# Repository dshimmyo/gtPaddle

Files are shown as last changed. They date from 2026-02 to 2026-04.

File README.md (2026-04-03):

# gtPaddle
paddle controller for gametank design files

# Images
Original Arduino experimental paddle:

arduinoPaddle

Protoboard paddle:

protoboardPaddle

PCB render:

rendering of pcb

---

License
This hardware documentation is licensed under the TAPR Open Hardware License.

(C) 2026 DKS Interactive LLC.
Based on the GameTank hardware designed by Clyde Shaffer

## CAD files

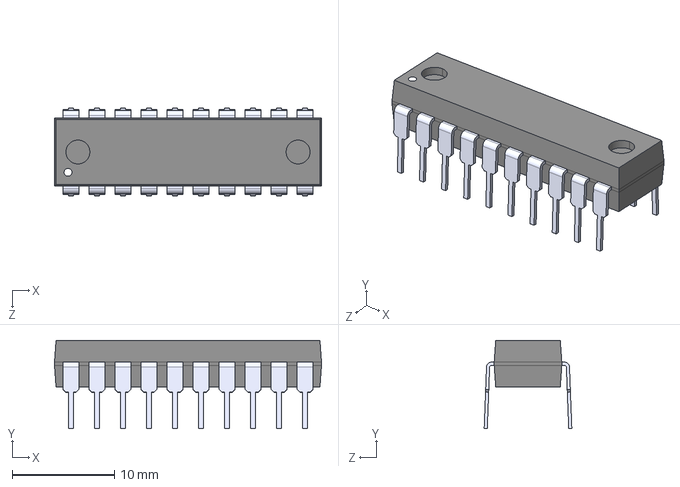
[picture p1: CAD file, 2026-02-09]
ADC0804LCN.step
26.1 x 8.64 x 8.56 mm

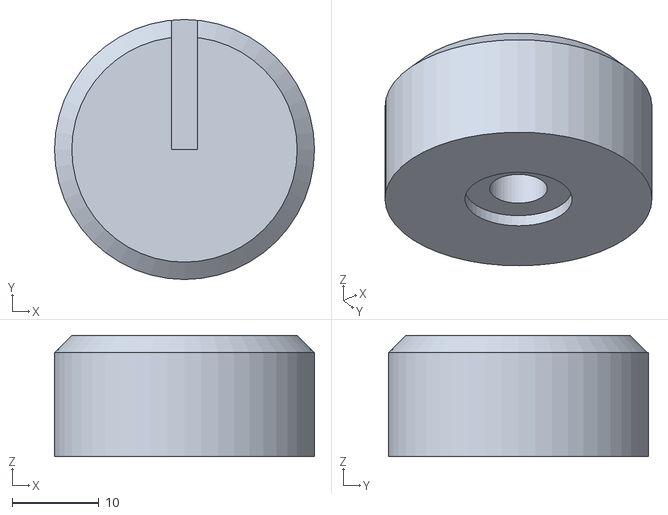
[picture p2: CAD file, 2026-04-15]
CAD/enclosure/2026-04-14/paddle knob 02.stl
30.0 x 30.0 x 14.0

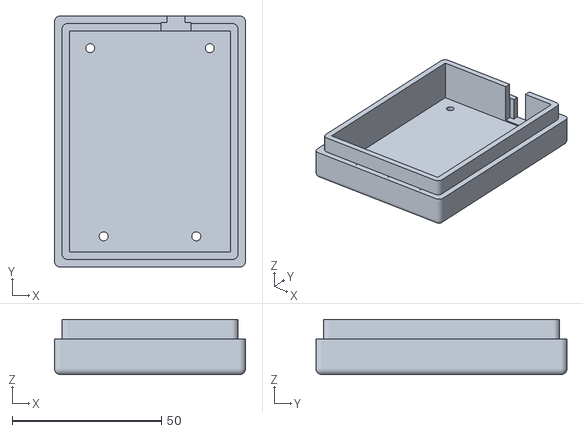
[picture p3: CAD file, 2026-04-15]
CAD/enclosure/2026-04-14/Paddle Enclosure 1 Bottom.stl
64.0 x 84.0 x 18.5

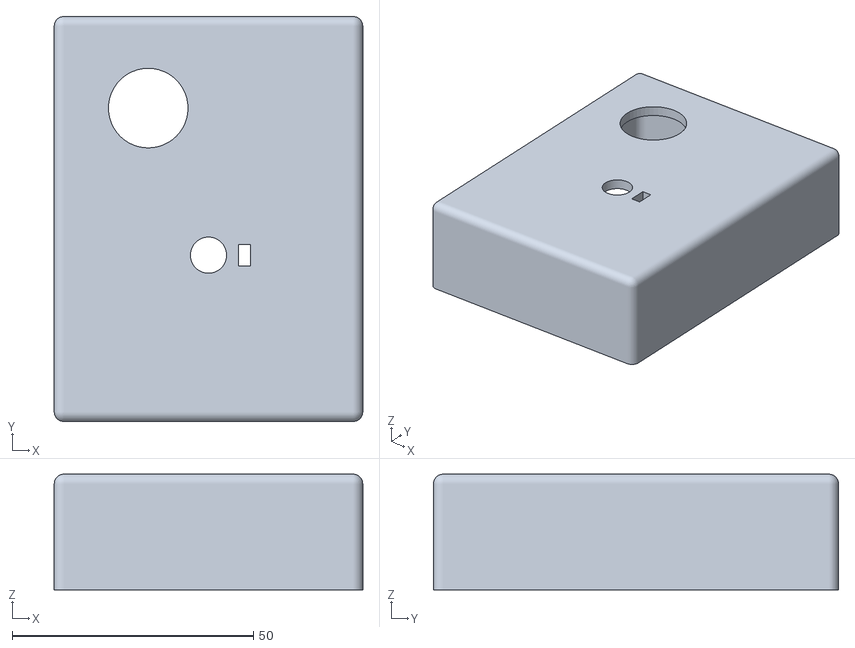
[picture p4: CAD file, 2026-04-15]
CAD/enclosure/2026-04-14/Paddle Enclosure 1.1 Top.stl
64.0 x 84.0 x 24.0

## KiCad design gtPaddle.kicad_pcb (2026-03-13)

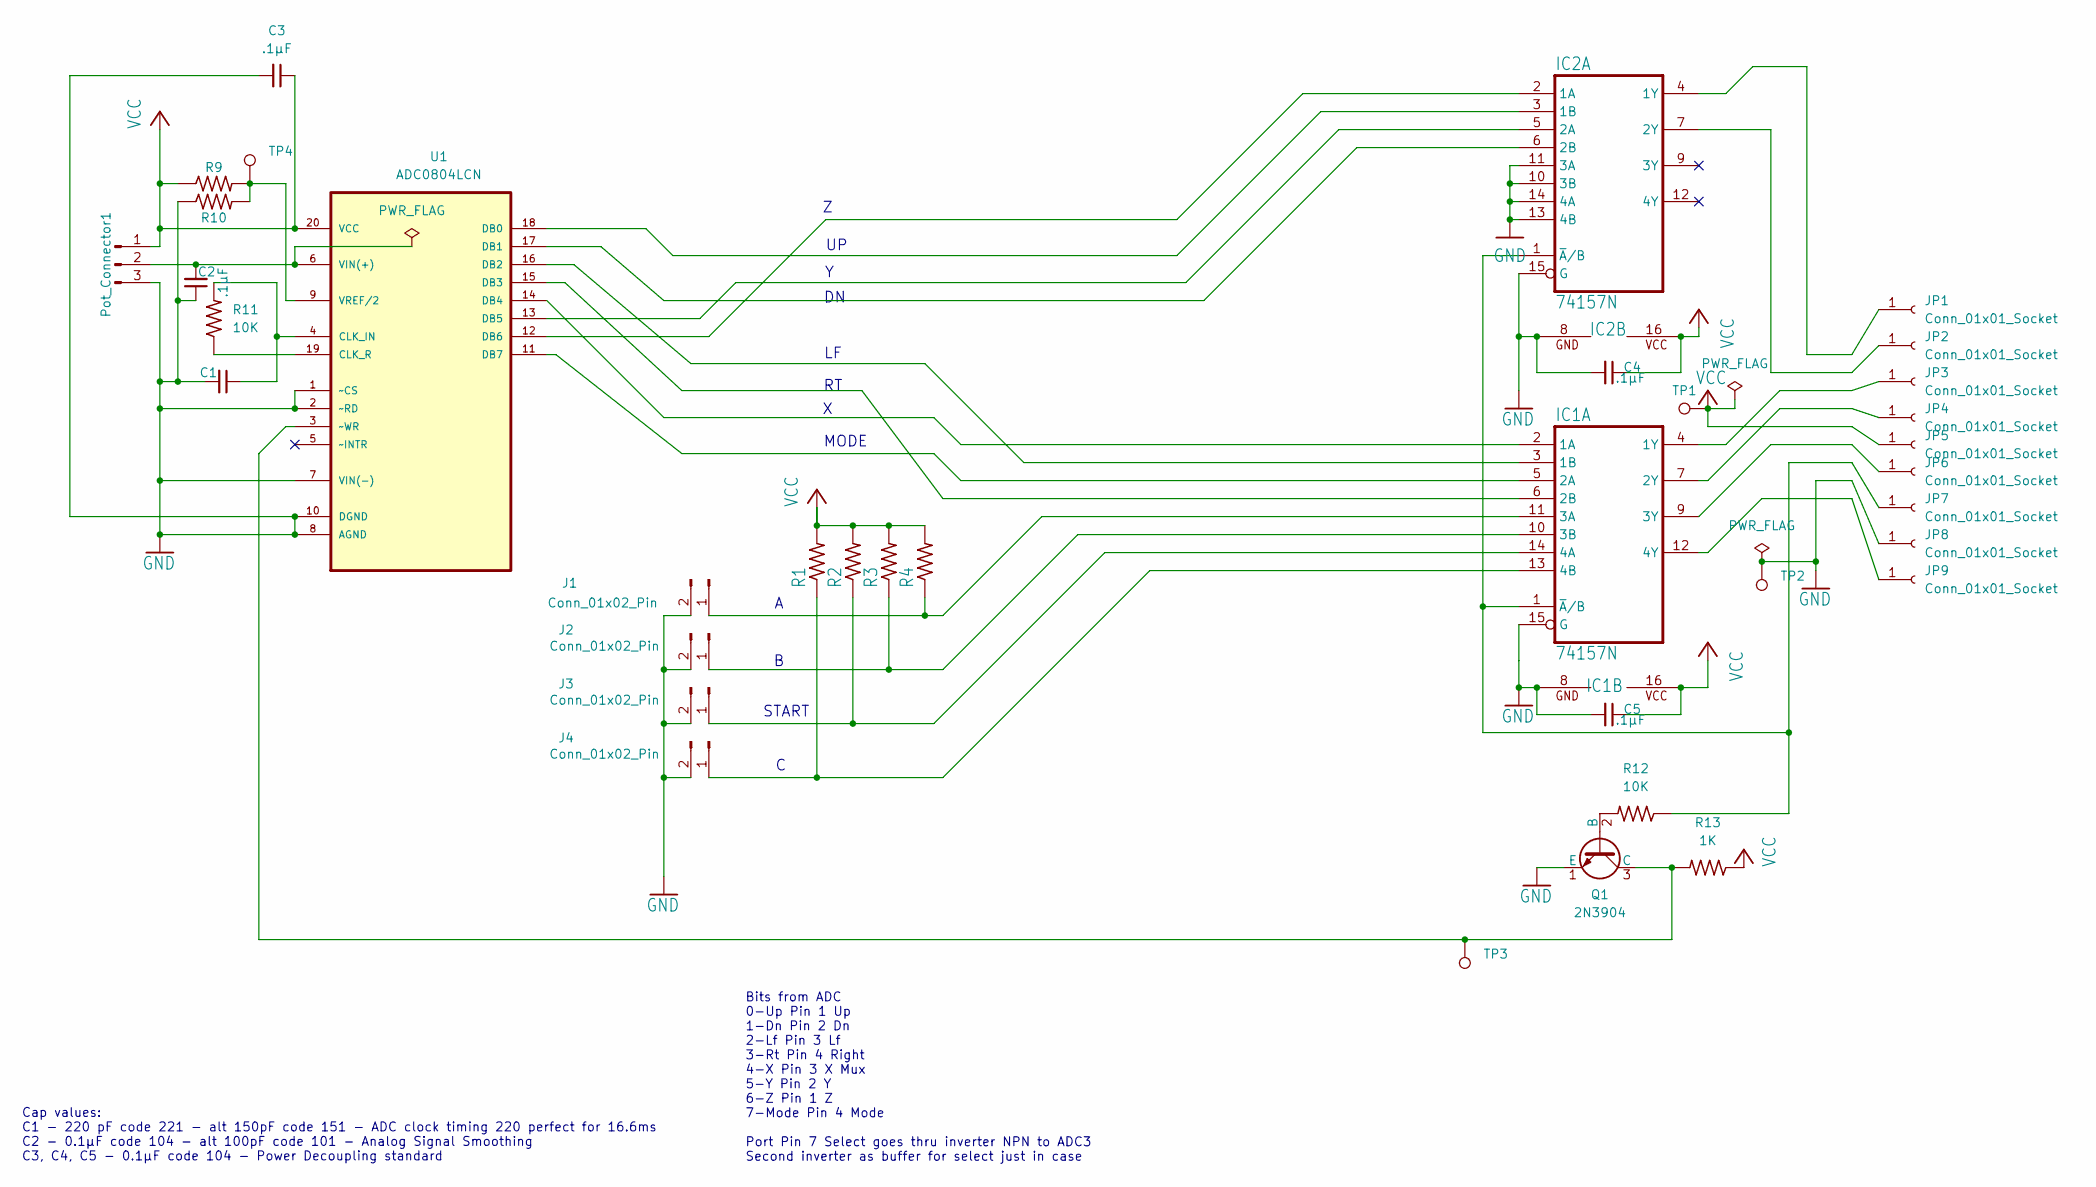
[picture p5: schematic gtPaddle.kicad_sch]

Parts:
C1: 220pF; C_Disc_D3.8mm_W2.6mm_P2.50mm
C2, C3, C4, C5: .1µF; C_Disc_D3.8mm_W2.6mm_P2.50mm
IC1, IC2: 74157N; DIL16
J1, J2, J3, J4: Conn_01x02_Pin; JST_PH_B2B-PH-K_1x02_P2.00mm_Vertical
JP1, JP2, JP3, JP4, JP5, JP6, JP7, JP8, JP9: Conn_01x01_Socket; SolderWire-0.75sqmm_1x01_D1.25mm_OD2.3mm
Pot_Connector1: Conn_01x03_Pin; JST_PH_B3B-PH-K_1x03_P2.00mm_Vertical
Q1: 2N3904; TO-92S-EBC
R1, R2, R3, R4: 3.3k; R_Axial_DIN0309_L9.0mm_D3.2mm_P2.54mm_Vertical
R9, R10, R13: 1K; R_Axial_DIN0309_L9.0mm_D3.2mm_P2.54mm_Vertical
R11, R12: 10K; R_Axial_DIN0309_L9.0mm_D3.2mm_P2.54mm_Vertical
TP1: VCC; TestPoint_THTPad_D1.5mm_Drill0.7mm
TP2: GND; TestPoint_THTPad_D1.5mm_Drill0.7mm
TP3: INV; TestPoint_THTPad_D1.5mm_Drill0.7mm
TP4: VREF; TestPoint_THTPad_D1.5mm_Drill0.7mm
U1: ADC0804LCN; DIP254P762X508-20; MPN ADC0804LCN

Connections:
GND: C1.2, C2.1, C3.2, C4.2, C5.2, IC1.8 (GND), IC1.15 (G), IC2.8 (GND), IC2.10 (3B), IC2.11 (3A), IC2.13 (4B), IC2.14 (4A), IC2.15 (G), J1.2, J2.2, J3.2, J4.2, JP8.1, Pot_Connector1.3, Q1.1 (E), R10.1, TP2.1, U1.1 (~CS), U1.2 (~RD), U1.7 (VIN(-)), U1.8 (AGND), U1.10 (DGND)
unnamed: IC1.2 (1A), U1.14 (DB4)
unnamed: IC1.3 (1B), U1.16 (DB2)
unnamed: IC1.4 (1Y), JP3.1
unnamed: IC1.5 (2A), U1.11 (DB7)
unnamed: IC1.6 (2B), U1.15 (DB3)
unnamed: IC1.7 (2Y), JP4.1
unnamed: IC1.11 (3A), J1.1, R4.1
unnamed: IC1.10 (3B), J2.1, R3.1
unnamed: IC1.9 (3Y), JP6.1
unnamed: IC1.14 (4A), J3.1, R2.1
unnamed: IC1.13 (4B), J4.1, R1.1
unnamed: IC1.12 (4Y), JP9.1
unnamed: IC1.1 (~A/B), IC2.1 (~A/B), JP7.1, R12.1
unnamed: IC2.2 (1A), U1.12 (DB6)
unnamed: IC2.3 (1B), U1.18 (DB0)
unnamed: IC2.4 (1Y), JP1.1
unnamed: IC2.5 (2A), U1.13 (DB5)
unnamed: IC2.6 (2B), U1.17 (DB1)
unnamed: IC2.7 (2Y), JP2.1
unnamed: C2.2, Pot_Connector1.2, U1.6 (VIN(+))
unnamed: Q1.2 (B), R12.2
unnamed: Q1.3 (C), R13.2, TP3.1, U1.3 (~WR)
unnamed: C1.1, R11.2, U1.4 (CLK_IN)
unnamed: R11.1, U1.19 (CLK_R)
unnamed: R9.2, R10.2, TP4.1, U1.9 (VREF/2)
VCC: C3.1, C4.1, C5.1, IC1.16 (VCC), IC2.16 (VCC), JP5.1, Pot_Connector1.1, R1.2, R2.2, R3.2, R4.2, R9.1, R13.1, TP1.1, U1.20 (VCC)

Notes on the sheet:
Cap values: C1 - 220 pF code 221 - alt 150pF code 151 - ADC clock timing 220 perfect for 16.6ms C2 - 0.1µF code 104 - alt 100pF code 101 - Analog Signal Smoothing C3, C4, C5 - 0.1µF code 104 - Power Decoupling standard
MODE
Bits from ADC 0-Up Pin 1 Up 1-Dn Pin 2 Dn 2-Lf Pin 3 Lf 3-Rt Pin 4 Right 4-X Pin 3 X Mux 5-Y Pin 2 Y 6-Z Pin 1 Z 7-Mode Pin 4 Mode Port Pin 7 Select goes thru inverter NPN to ADC3 Second inverter as buffer for select just in case
START

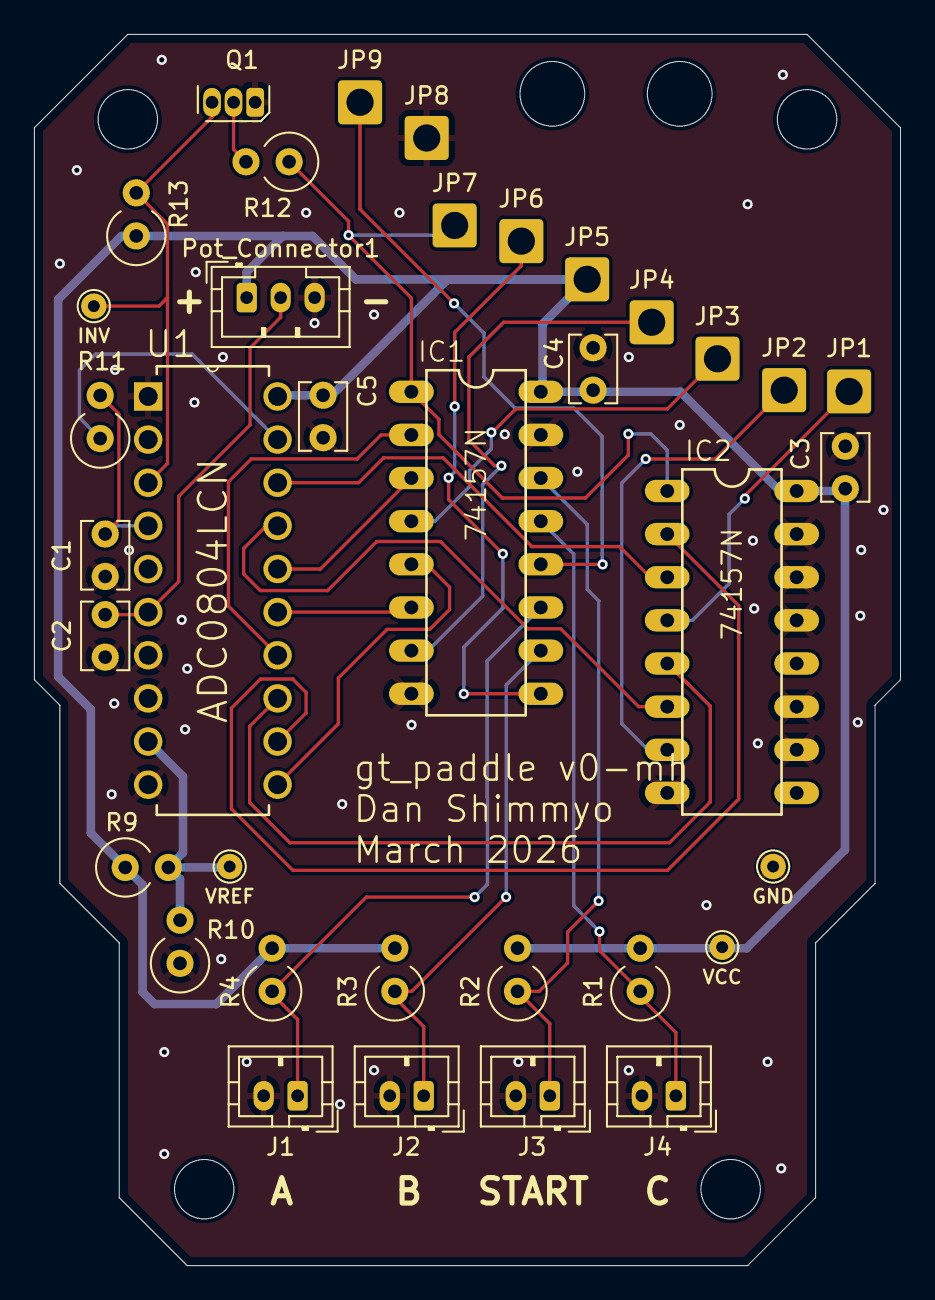
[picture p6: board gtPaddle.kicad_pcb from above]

Board: 2 copper layers, 51.0 x 72.5 mm, 36 parts (0 on the bottom side), 27 nets.

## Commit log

2026-02-09 imported footprints and symbols from gpad1
    [ADC0804LCN.step, gtPaddle.kicad_pcb, gtPaddle.kicad_sch]
2026-02-09 added more BJT switches
    [gtPaddle.kicad_sch]
2026-02-10 completed adding all of the bit bjt switches, added two new bjt selector circuits, added select signal inverter/booster. Still needs reference voltage on ADC
    [gtPaddle.kicad_sch]
2026-02-10 ADC connections done
    [gtPaddle.kicad_sch]
2026-02-10 some cleanup
    [gtPaddle.kicad_sch]
2026-02-10 minor edits
    [gtPaddle.kicad_sch]
2026-02-11 added filter cap to pot
    [gtPaddle.kicad_sch]
2026-02-17 consistent resistor values for calculating order
    [gtPaddle.kicad_sch]
2026-02-27 reversed, but maybe a mistake
    [gtPaddle.kicad_sch]
2026-02-27 add dual select inverters
    [gtPaddle.kicad_sch]
2026-03-04 much simplified design
    [gtPaddle.kicad_sch]
2026-03-04 more simplified
    [gtPaddle.kicad_sch]
2026-03-04 some wire cleanup
    [gtPaddle.kicad_sch]
2026-03-04 remove second inverter from select
    [gtPaddle.kicad_sch]
2026-03-05 Gemini helped me update my schematic. pullups on unused mux inputs and unused outputs left floating decoupling caps on each IC. Faster switching on the inverter for earlier ADC triggering
    [gtPaddle.kicad_sch]
2026-03-09 capacitor notes added
    [gtPaddle.kicad_sch]
2026-03-09 picking cap values that are easier to stock, and use common values
    [gtPaddle.kicad_sch]
2026-03-09 swapped JST connectors for buttons
    [gtPaddle.kicad_sch]
2026-03-09 renamed Resistors, added power flags for ERC, added a no connect
    [gtPaddle.kicad_sch]
2026-03-09 added only one npn mux but not hooked up yet
    [gtPaddle.kicad_sch]
2026-03-09 new npn mux still not hooked up but the schematic looks nicer
    [gtPaddle.kicad_sch]
2026-03-09 added soldered jumpers bridged and unbridged to handle optional setups
    [gtPaddle.kicad_sch]
2026-03-09 dual npn mux option added to schematic
    [gtPaddle.kicad_sch]
2026-03-10 footprint assignments
    [gtPaddle.kicad_sch]
2026-03-10 start removing old pcb edits
    [gtPaddle.kicad_pcb]
2026-03-10 start placing mux and adc
    [gtPaddle.kicad_pcb]
2026-03-10 first pass placement no traces
    [gtPaddle.kicad_pcb, gtPaddle.kicad_sch]
2026-03-10 layout tweaks
    [gtPaddle.kicad_pcb]
2026-03-10 pcb commit before rotating npn mux
    [gtPaddle.kicad_pcb]
2026-03-10 tighter layout
    [gtPaddle.kicad_pcb, gtPaddle.kicad_sch]
2026-03-10 edited bjt footprint
    [gtPaddle.kicad_pcb, gtPaddle.kicad_sch]
2026-03-10 compact layout
    [gtPaddle.kicad_pcb]
2026-03-11 more compact
    [gtPaddle.kicad_pcb]
2026-03-11 ground unused mux pins
    [gtPaddle.kicad_sch]
2026-03-11 started drawing traces
    [gtPaddle.kicad_pcb]
2026-03-11 power routing
    [gtPaddle.kicad_pcb]
2026-03-11 more trace work but not happy
    [gtPaddle.kicad_pcb]
2026-03-11 removed extra resistors from pcb layout
    [gtPaddle.kicad_pcb]
2026-03-11 remove npn muxes
    [gtPaddle.kicad_pcb, gtPaddle.kicad_sch]
2026-03-11 eliminated errors
    [gtPaddle.kicad_pcb]
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2026-03-11 some cleaning
    [gtPaddle.kicad_pcb]
2026-03-11 left right up flow
    [gtPaddle.kicad_pcb]
2026-03-11 filled a blank spot
    [gtPaddle.kicad_pcb]
2026-03-12 clean up traces, add vias
    [gtPaddle.kicad_pcb]
2026-03-12 enough edits for one night
    [gtPaddle.kicad_pcb]
2026-03-12 muxes moved up
    [gtPaddle.kicad_pcb]
2026-03-12 Individual headers first pass
    [gtPaddle.kicad_pcb, gtPaddle.kicad_sch]
2026-03-12 spent too much time fanning out the headers
    [gtPaddle.kicad_pcb]
2026-03-12 angular shape
    [gtPaddle.kicad_pcb]
2026-03-12 moved teeth up
    [gtPaddle.kicad_pcb]
2026-03-12 checking edge cuts and mounting points
    [gtPaddle.kicad_pcb]
2026-03-12 precise edge cuts
    [gtPaddle.kicad_pcb]
2026-03-12 add missing models
    [gtPaddle.kicad_pcb]
2026-03-12 move pot inward
    [gtPaddle.kicad_pcb]
2026-03-12 add missing npn model
    [gtPaddle.kicad_pcb]
2026-03-13 groundplane stitching
    [gtPaddle.kicad_pcb]
2026-03-13 silkscreen text updates
    [gtPaddle.kicad_pcb]
2026-03-13 add testpoints, ocd edits
    [gtPaddle.kicad_pcb, gtPaddle.kicad_sch]
2026-03-13 add signature on back
    [gtPaddle.kicad_pcb]
2026-03-13 signature adjust
    [gtPaddle.kicad_pcb]
2026-03-13 pcbway product number placement silkscreen
    [gtPaddle.kicad_pcb]
2026-03-13 add capacitor labels to silkscreen
    [gtPaddle.kicad_pcb]
2026-03-13 restored corner holes
    [gtPaddle.kicad_pcb]
2026-03-13 restored unnamed mounting holes
    [gtPaddle.kicad_pcb]
2026-03-13 fixed waywayway and via
    [gtPaddle.kicad_pcb]
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2026-03-13 updated version number to v1-mh for mounting holes edition
    [gtPaddle.kicad_pcb]
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2026-03-18 committing after gerber gen
    [gtPaddle copy.kicad_pcb]
2026-03-25 added license note to title block
    [gtPaddle.kicad_sch]
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2026-04-07 created hybrid ADC footprint and added to pcb layout
    [ADC0804LCWM.step, gtPaddle.kicad_pcb, gtPaddle.kicad_sch]
2026-04-07 3d model edit trace routing cleanup
    [gtPaddle.kicad_pcb]
2026-04-07 silkscreen tweaks
    [gtPaddle.kicad_pcb]
2026-04-08 restored 5 mounting holes
    [gtPaddle.kicad_pcb]
2026-04-08 restored final mounting hole. Locked mounting holes.
    [gtPaddle.kicad_pcb]
2026-04-08 bigger NPN footprint, better for hand-soldering
    [gtPaddle.kicad_pcb, gtPaddle.kicad_sch]
2026-04-09 enlarge holes for jst connectors
    [gtPaddle.kicad_pcb, gtPaddle.kicad_sch]
2026-04-15 stl files
    [Paddle Enclosure 1 Bottom.stl, Paddle Enclosure 1.1 Top.stl, paddle knob 02.stl]
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
